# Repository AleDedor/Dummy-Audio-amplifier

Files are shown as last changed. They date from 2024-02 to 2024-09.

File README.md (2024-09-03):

# Dummy-Audio-amplifier
A very basic, 2-stages, audio amplifier, designed with discrete THT components. 
The goal of the project is to build from scratch a simple audio amplifier in order to get familiarity with the main issues of the audio world.

## Main concerns:

- **Noise level**, keep it as low as possible adding decoupling capacitor as close as possible to the LM741 amplifiers (switching noise of the DCDC converter) and using low value resistors (Thermal noise).
- **Limited Bandwidth**, in order to reduce noise r.m.s. and filter out external disturbs.
- **Push-pull final stage thermal runaway**, biasing BJTs with fixed base-emitter voltage cause high dependance on temperature. Introduce emitter resistance to counteract.
- Compensate for Loudspeaker increasing impedance over audio bandwidth with a **Zobel network**.
- Avoid **loop instability** (output stage).

## Soldered PCB image:
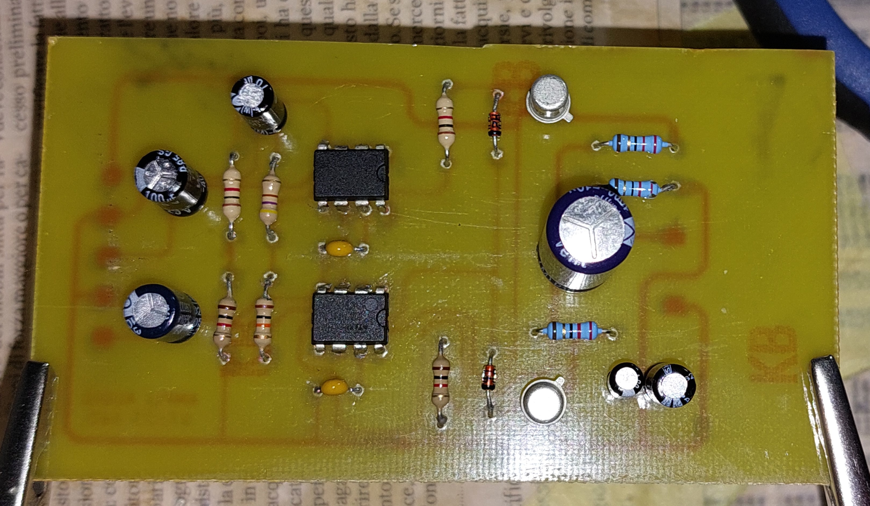
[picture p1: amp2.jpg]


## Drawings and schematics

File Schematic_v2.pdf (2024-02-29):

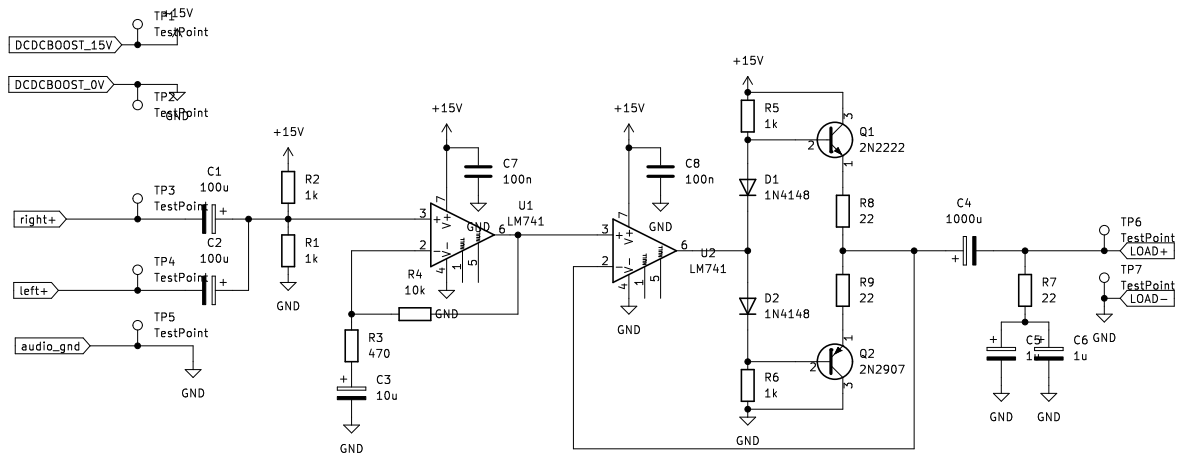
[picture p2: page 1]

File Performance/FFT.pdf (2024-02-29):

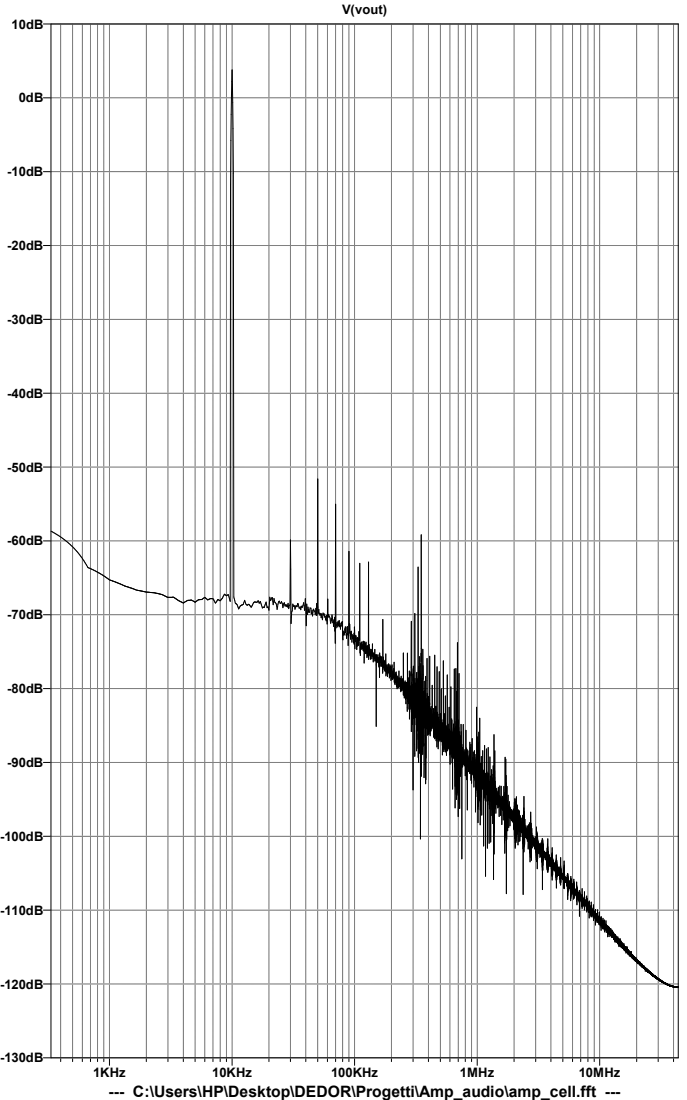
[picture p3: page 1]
1KHz; 10KHz; 100KHz; 1MHz; 10MHz; V(vout)

--- C:\Users\HP\Desktop\DEDOR\Progetti\Amp_audio\amp_cell.fft ---

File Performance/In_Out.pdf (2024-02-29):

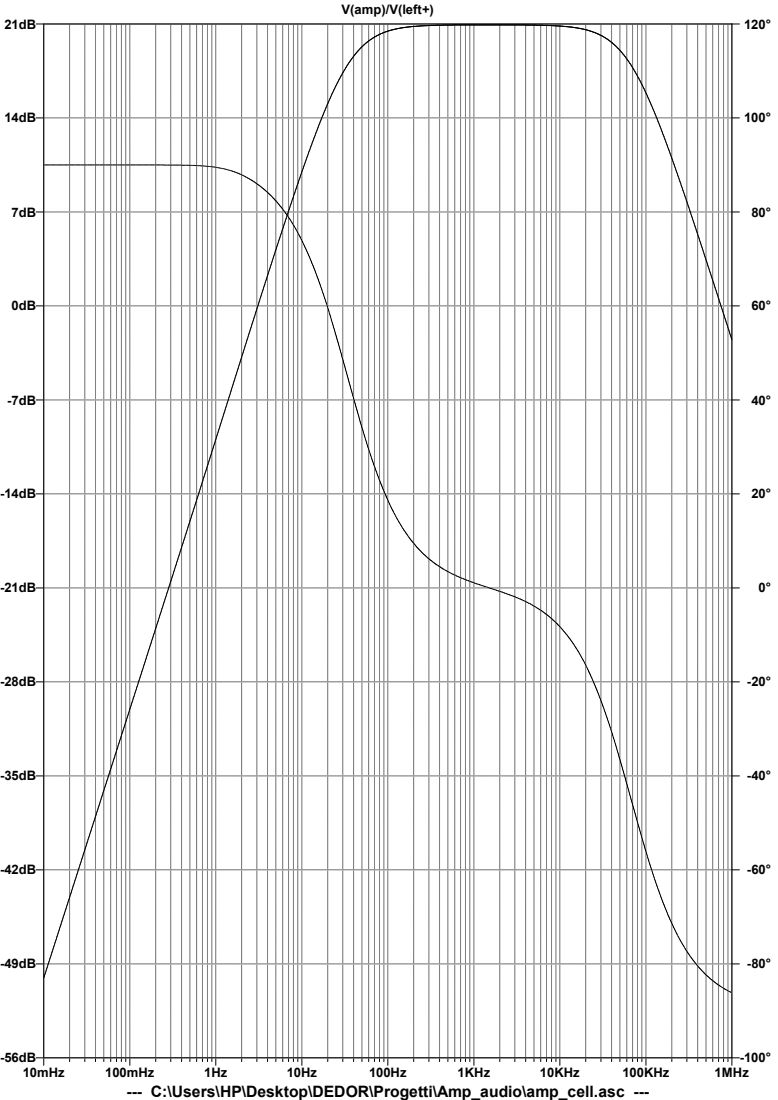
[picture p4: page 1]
10mHz; 100mHz; 1KHz; 10KHz; 100KHz; 1MHz; V(amp)/V(left+)

--- C:\Users\HP\Desktop\DEDOR\Progetti\Amp_audio\amp_cell.asc ---

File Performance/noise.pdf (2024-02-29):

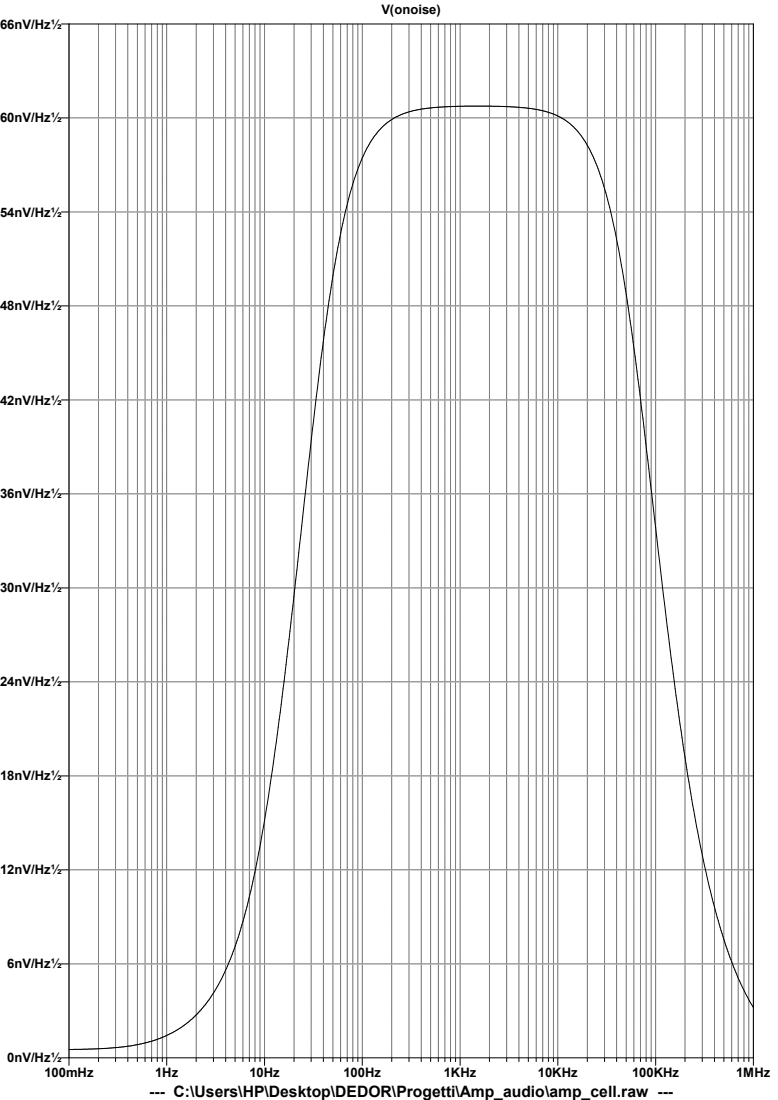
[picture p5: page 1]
100mHz; 1KHz; 10KHz; 100KHz; 1MHz; 0nV/Hz½; 6nV/Hz½; 12nV/Hz½; 18nV/Hz½; 24nV/Hz½; 30nV/Hz½; 36nV/Hz½; 42nV/Hz½; 48nV/Hz½; 54nV/Hz½; 60nV/Hz½; 66nV/Hz½; V(onoise)

--- C:\Users\HP\Desktop\DEDOR\Progetti\Amp_audio\amp_cell.raw ---

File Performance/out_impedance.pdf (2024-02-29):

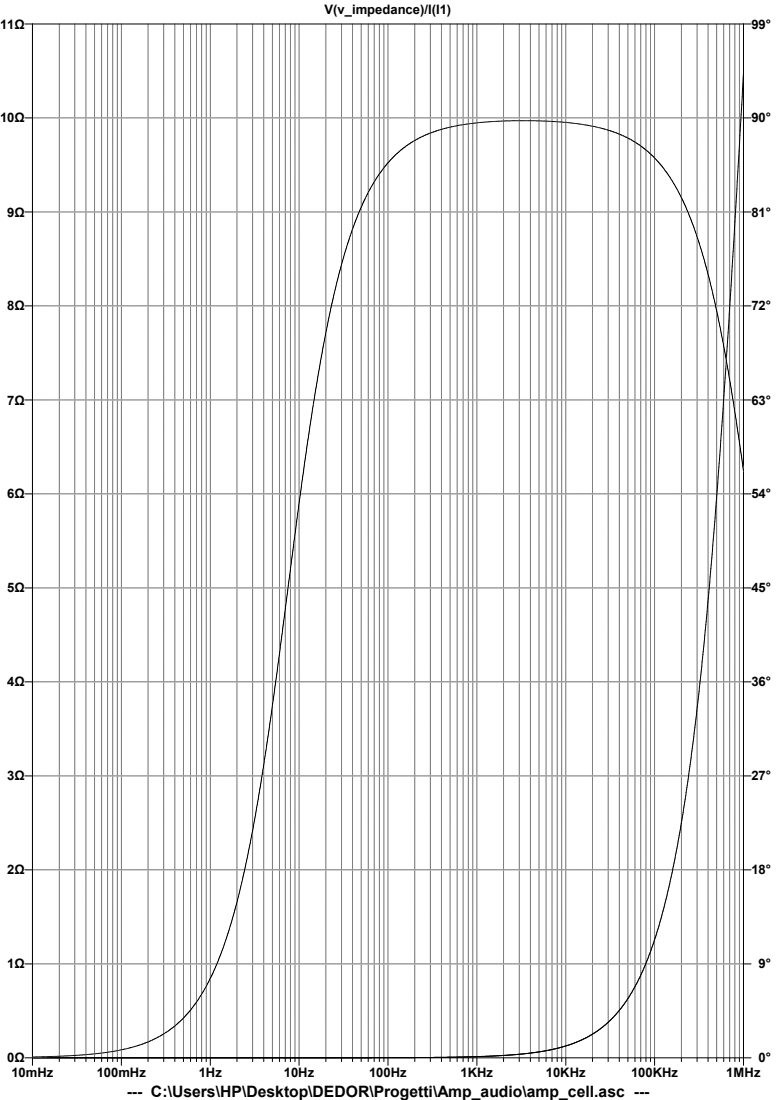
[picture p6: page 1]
10mHz; 100mHz; 1KHz; 10KHz; 100KHz; 1MHz; V(v_impedance)/I(I1)

--- C:\Users\HP\Desktop\DEDOR\Progetti\Amp_audio\amp_cell.asc ---

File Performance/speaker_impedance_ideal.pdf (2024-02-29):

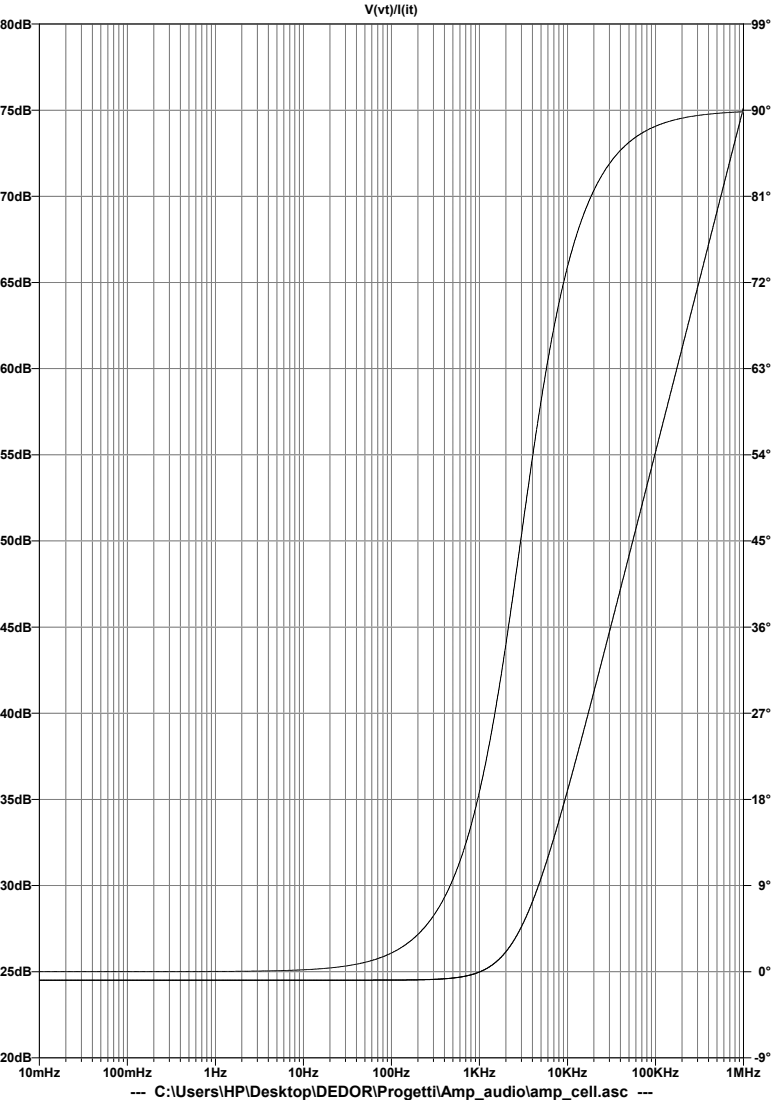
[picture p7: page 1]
10mHz; 100mHz; 1KHz; 10KHz; 100KHz; 1MHz

--- C:\Users\HP\Desktop\DEDOR\Progetti\Amp_audio\amp_cell.asc ---

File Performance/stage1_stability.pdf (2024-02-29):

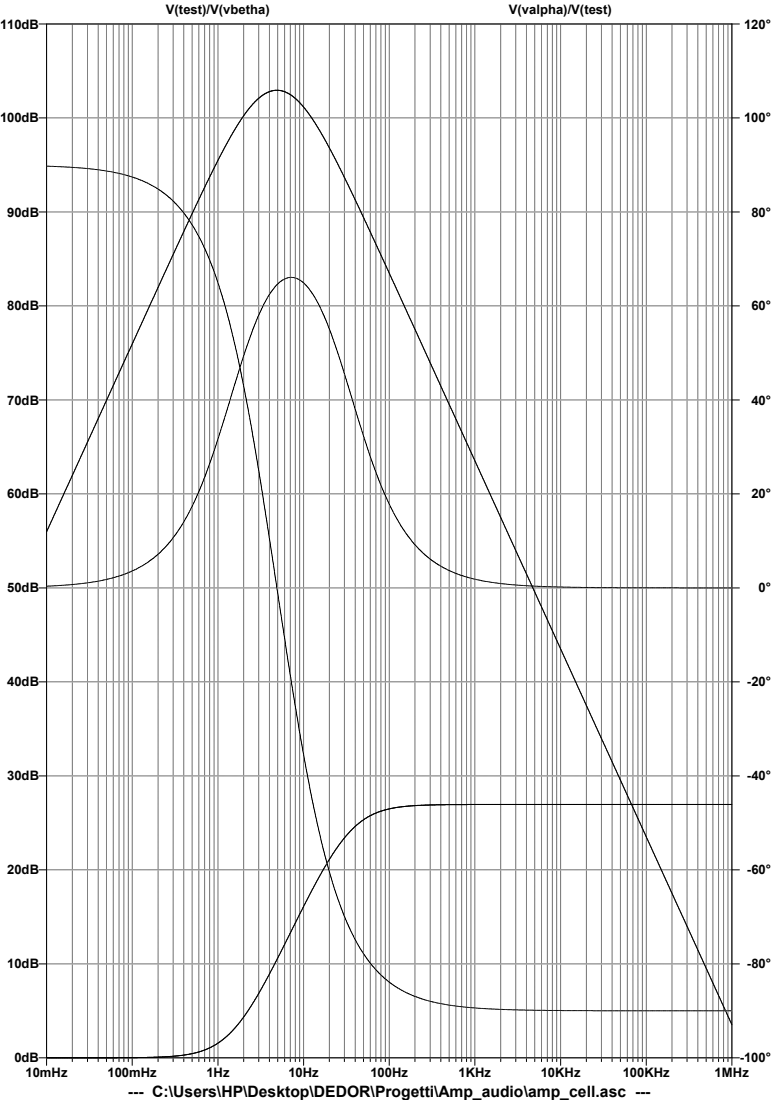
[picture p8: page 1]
10mHz; 100mHz; 1KHz; 10KHz; 100KHz; 1MHz; V(test)/V(vbetha); V(valpha)/V(test)

--- C:\Users\HP\Desktop\DEDOR\Progetti\Amp_audio\amp_cell.asc ---

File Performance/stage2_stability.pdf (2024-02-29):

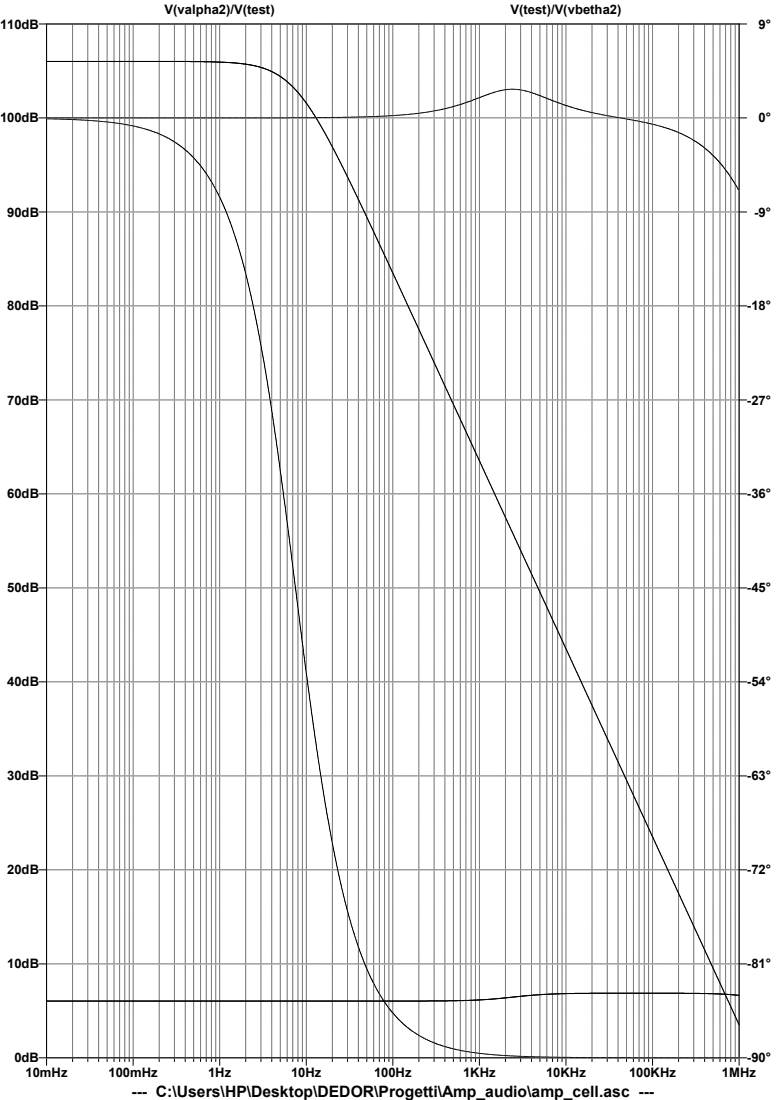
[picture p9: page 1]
10mHz; 100mHz; 1KHz; 10KHz; 100KHz; 1MHz; V(valpha2)/V(test); V(test)/V(vbetha2)

--- C:\Users\HP\Desktop\DEDOR\Progetti\Amp_audio\amp_cell.asc ---

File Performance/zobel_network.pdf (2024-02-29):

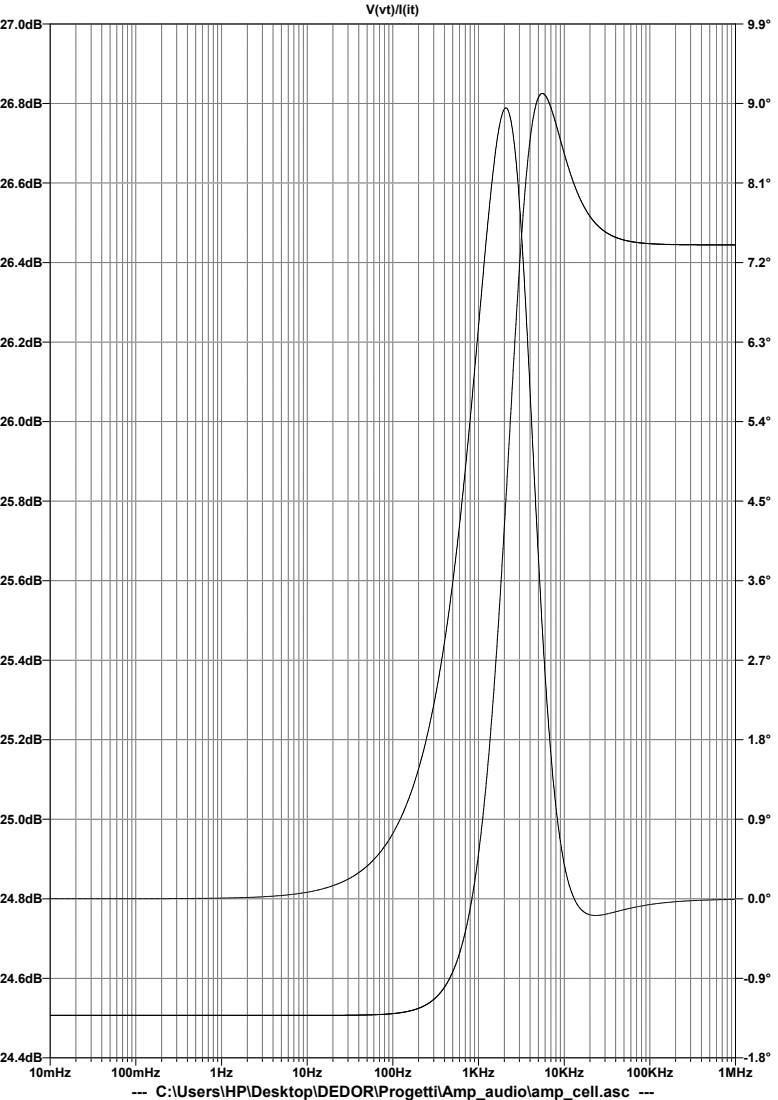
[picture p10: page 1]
10mHz; 100mHz; 1KHz; 10KHz; 100KHz; 1MHz

--- C:\Users\HP\Desktop\DEDOR\Progetti\Amp_audio\amp_cell.asc ---

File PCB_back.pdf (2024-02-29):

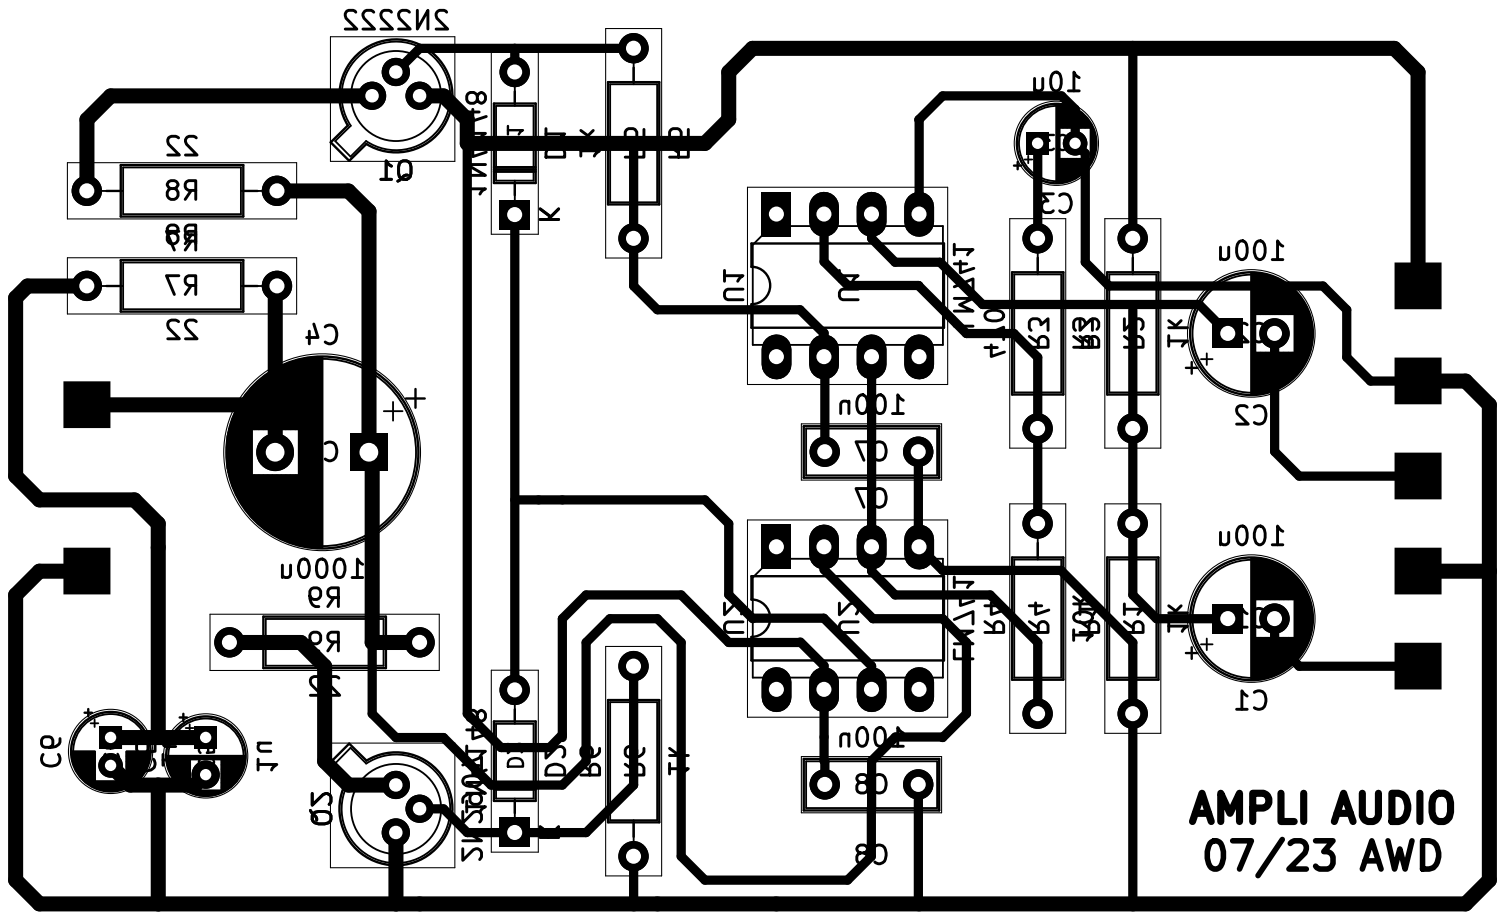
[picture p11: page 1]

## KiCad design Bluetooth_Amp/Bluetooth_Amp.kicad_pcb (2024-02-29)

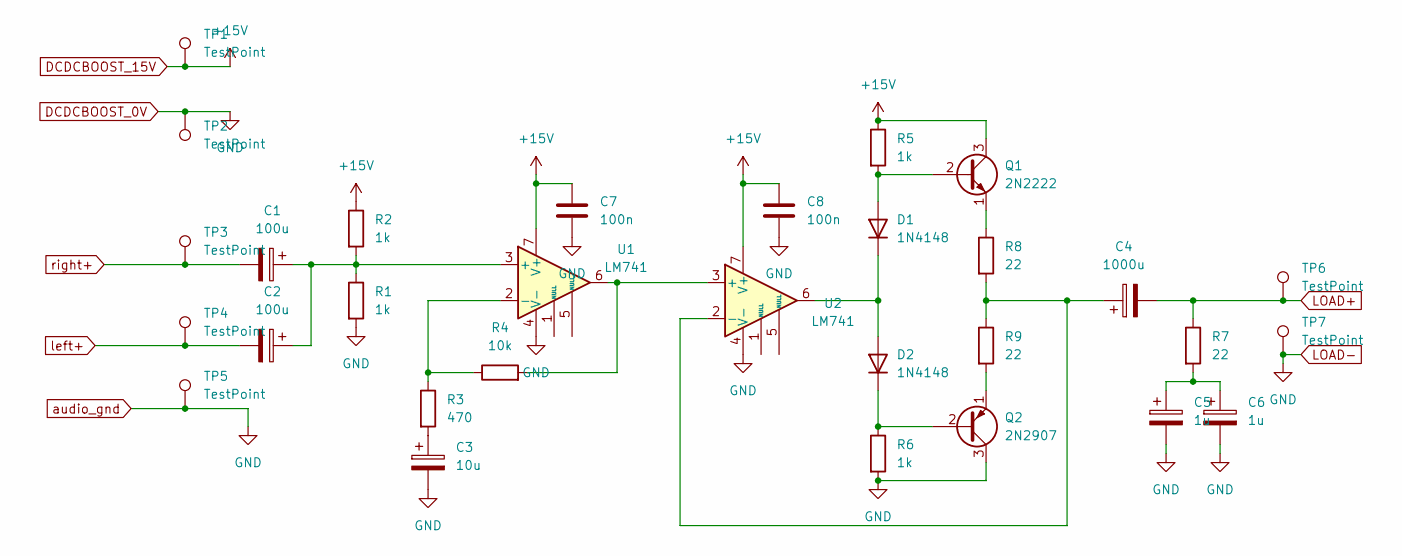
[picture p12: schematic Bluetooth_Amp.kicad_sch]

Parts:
C1, C2: 100u; CP_Radial_D6.3mm_P2.50mm
C3: 10u; CP_Radial_D4.0mm_P2.00mm
C4: 1000u; CP_Radial_D10.0mm_P5.00mm
C5: 1u; CP_Radial_D4.0mm_P2.00mm
C6: 1u; CP_Radial_D4.0mm_P1.50mm
C7, C8: 100n; C_Rect_L7.0mm_W2.5mm_P5.00mm
D1, D2: 1N4148; D_DO-35_SOD27_P7.62mm_Horizontal
Q1: 2N2222; TO-18-3
Q2: 2N2907; TO-18-3
R1, R2, R5, R6: 1k; R_Axial_DIN0207_L6.3mm_D2.5mm_P10.16mm_Horizontal
R3: 470; R_Axial_DIN0207_L6.3mm_D2.5mm_P10.16mm_Horizontal
R4: 10k; R_Axial_DIN0207_L6.3mm_D2.5mm_P10.16mm_Horizontal
R7, R8, R9: 22; R_Axial_DIN0207_L6.3mm_D2.5mm_P10.16mm_Horizontal
TP1, TP2, TP3, TP4, TP5, TP6, TP7: TestPoint; TestPoint_Pad_2.5x2.5mm
U1, U2: LM741; DIP-8_W7.62mm_LongPads

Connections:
DCDCBOOST_0V: C3.2, C5.2, C6.2, C7.2, C8.2, Q2.3 (C), R1.2, R6.2, TP2.1, TP5.1, TP7.1, U1.4 (V-), U2.4 (V-)
DCDCBOOST_15V: C7.1, C8.1, Q1.3 (C), R2.1, R5.1, TP1.1, U1.7 (V+), U2.7 (V+)
LOAD+: C4.2, R7.1, TP6.1
unnamed: C1.1, C2.1, R1.1, R2.2, U1.3 (+)
unnamed: C3.1, R3.2
unnamed: C4.1, R8.2, R9.1, U2.2 (-)
unnamed: C5.1, C6.1, R7.2
unnamed: D1.1 (K), D2.2 (A), U2.6
unnamed: D1.2 (A), Q1.2 (B), R5.2
unnamed: D2.1 (K), Q2.2 (B), R6.1
unnamed: Q1.1 (E), R8.1
unnamed: Q2.1 (E), R9.2
unnamed: R3.1, R4.1, U1.2 (-)
unnamed: R4.2, U1.6, U2.3 (+)
left+: C2.2, TP4.1
right+: C1.2, TP3.1

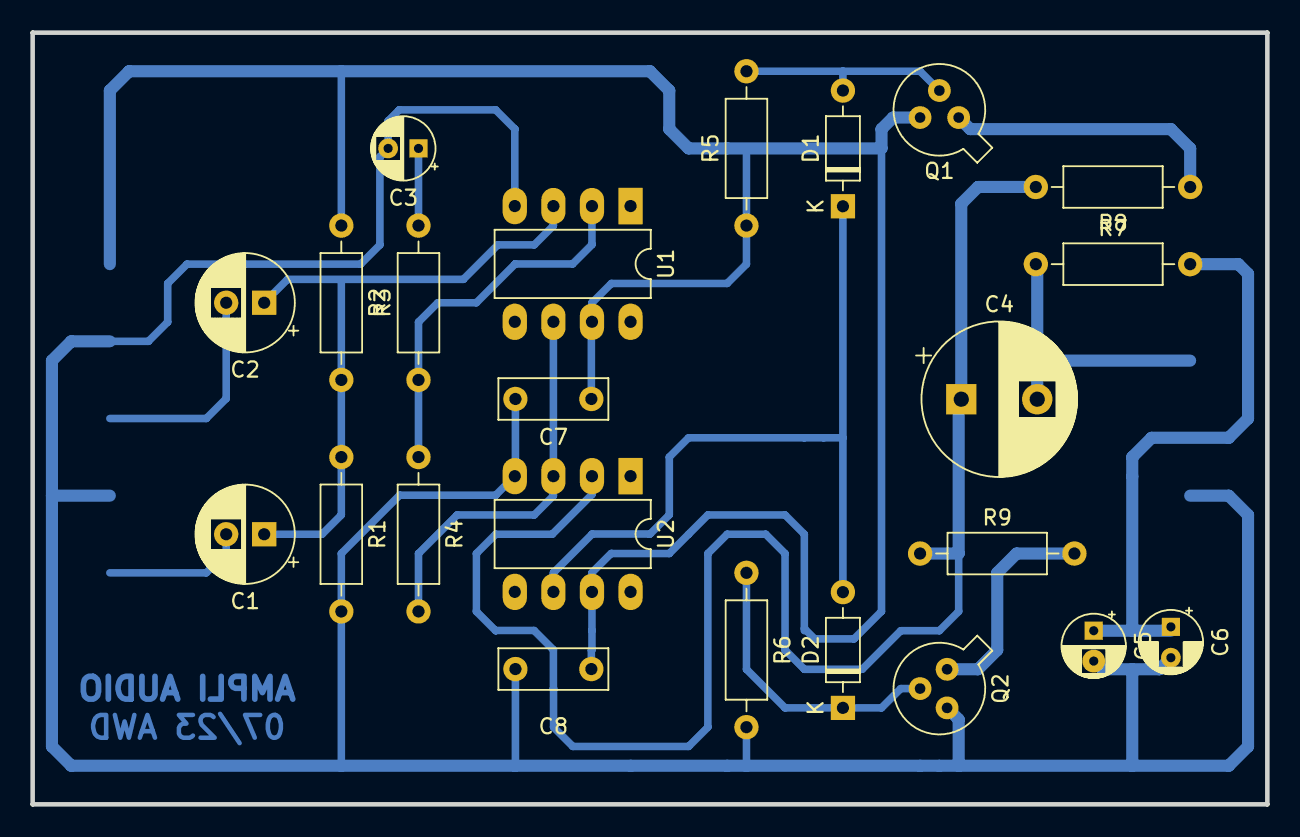
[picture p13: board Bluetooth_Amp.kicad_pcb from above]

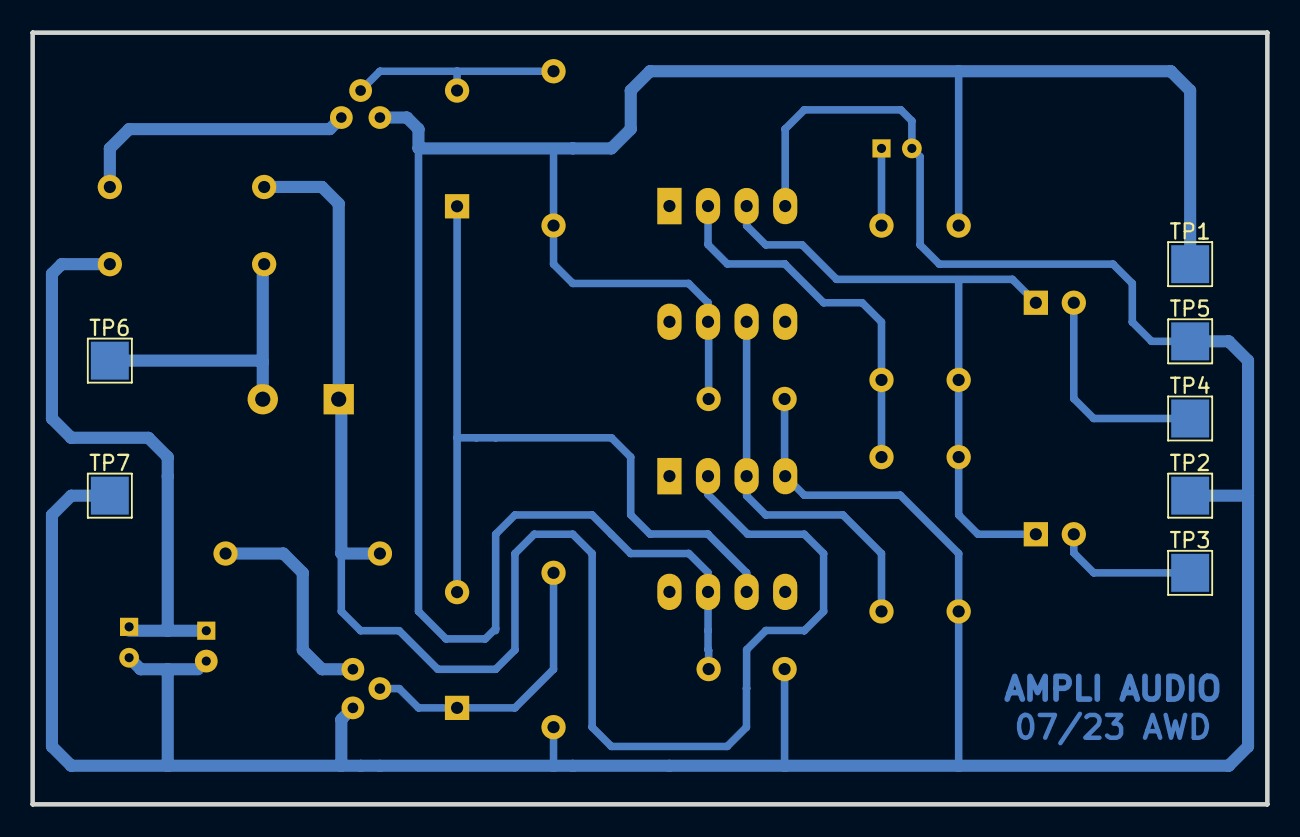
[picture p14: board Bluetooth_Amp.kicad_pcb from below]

Board: 2 copper layers, 81.3 x 50.8 mm, 30 parts (7 on the bottom side), 16 nets.

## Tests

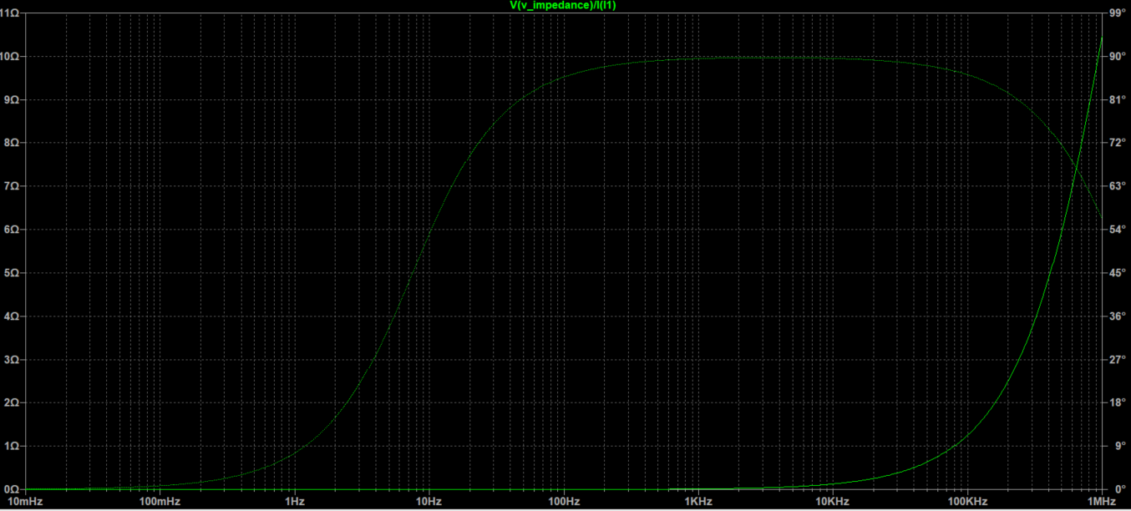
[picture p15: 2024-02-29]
Performance/out_imped_bode.PNG

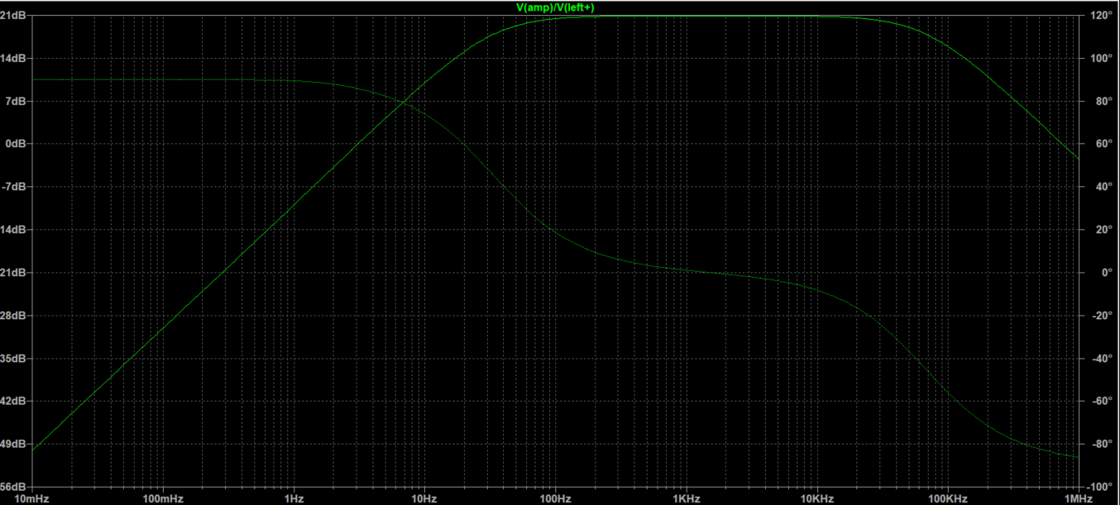
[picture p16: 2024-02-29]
Performance/in_out.png

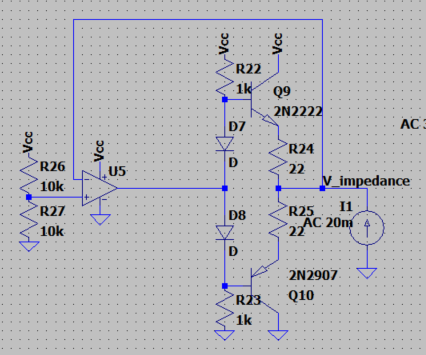
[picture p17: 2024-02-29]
Performance/out_imped.PNG

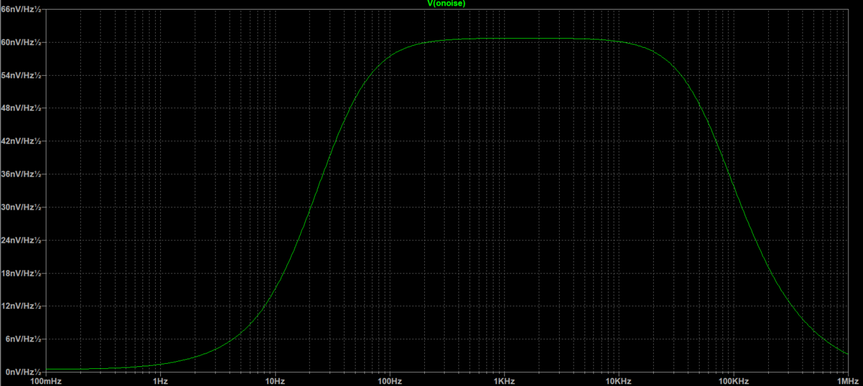
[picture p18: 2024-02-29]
Performance/noise.png

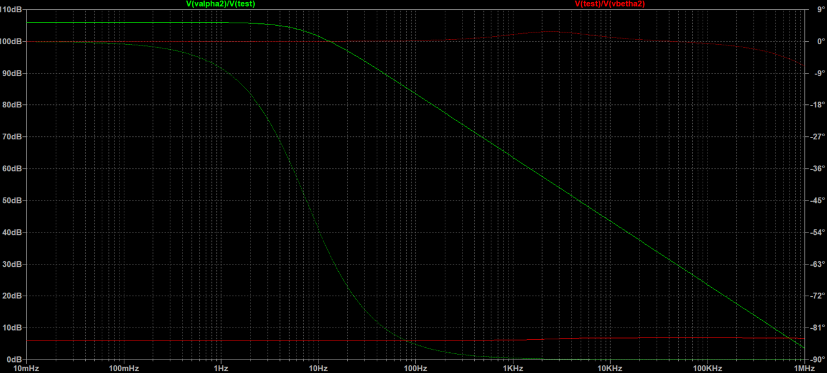
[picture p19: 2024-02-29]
Performance/stage2_stable.png

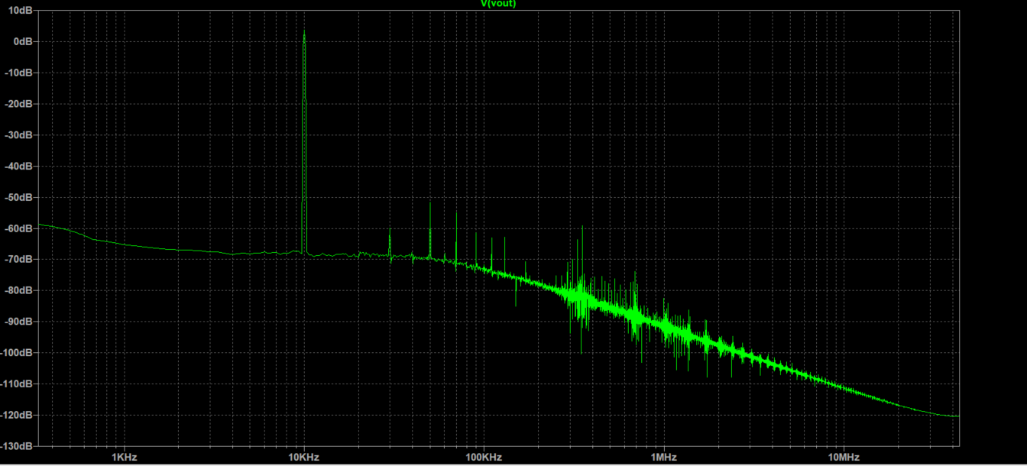
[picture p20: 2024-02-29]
Performance/FFT.PNG

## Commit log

2024-02-29 Added all files
    [Bluetooth_Amp.kicad_pcb, Bluetooth_Amp.kicad_sch]
2024-09-03 final pcb image
